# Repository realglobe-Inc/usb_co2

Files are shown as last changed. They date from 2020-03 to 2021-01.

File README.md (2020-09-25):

# usb_co2

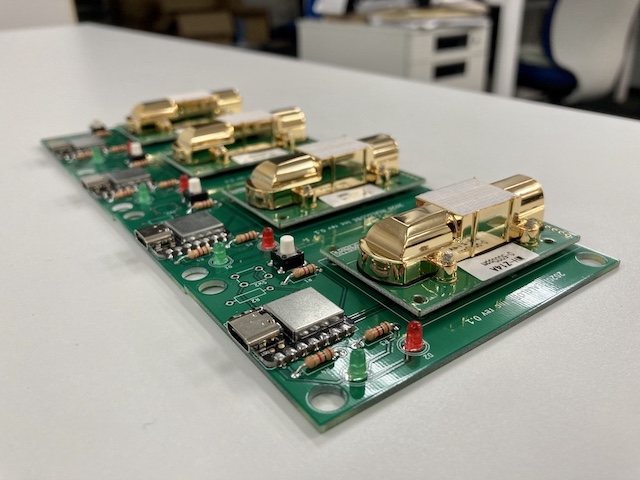
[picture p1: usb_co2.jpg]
usb_co2


Mac, LinuxマシンにUSBで接続できて追加ドライバ不要で値を読めるCO2センサ

## 使い方(macOS)

まず、USB機器をすべてコンピュータから取り外す。

次に、usb_co2をUSBポートに接続する。

次に、コンピュータに接続されているシリアルポートの一覧を表示する。

```
$ ls -1 /dev/cu.*
/dev/cu.Bluetooth-Incoming-Port
/dev/cu.iMiminashi5s-WirelessiAP
/dev/cu.usbmodem14101
```

上記の例の場合、`cu.usbmodem14101` というデバイスファイルがusb_co2を示す。

次に、`stty`コマンドを実行してシリアルポートの設定を行う。

```sh
stty -f /dev/cu.usbmodem14101 raw 9600
```

最後に、`cat`コマンドでデバイスファイルを読み込むとCO2の値(ppm)が表示される。

```
$ cat /dev/cu.usbmodem14101 
co2=399;status=0
co2=399;status=0
co2=399;status=0
co2=399;status=0
co2=399;status=0
co2=399;status=0
```

## 使い方(Linux)

まず、USB機器をすべてコンピュータから取り外す。

次に、usb_co2をUSBポートに接続する。

次に、コンピュータに接続されているシリアルポートの一覧を表示する。

```
$ ls -1 /dev/tty*
/dev/tty
.
. (中略)
.
/dev/ttyACM0
/dev/ttyAMA0
/dev/ttyprintk
/dev/ttyUSB0
```

上記の例の場合、`/dev/ttyACM0` というデバイスファイルがusb_co2を示す。

次に、`stty`コマンドを実行してシリアルポートの設定を行う。

```sh
stty -F /dev/ttyACM0 raw 9600
```

最後に、`cat`コマンドでデバイスファイルを読み込むとCO2の値(ppm)が表示される。

```
$ cat /dev/ttyACM0
co2=399;status=0
co2=399;status=0
co2=399;status=0
co2=399;status=0
co2=399;status=0
```

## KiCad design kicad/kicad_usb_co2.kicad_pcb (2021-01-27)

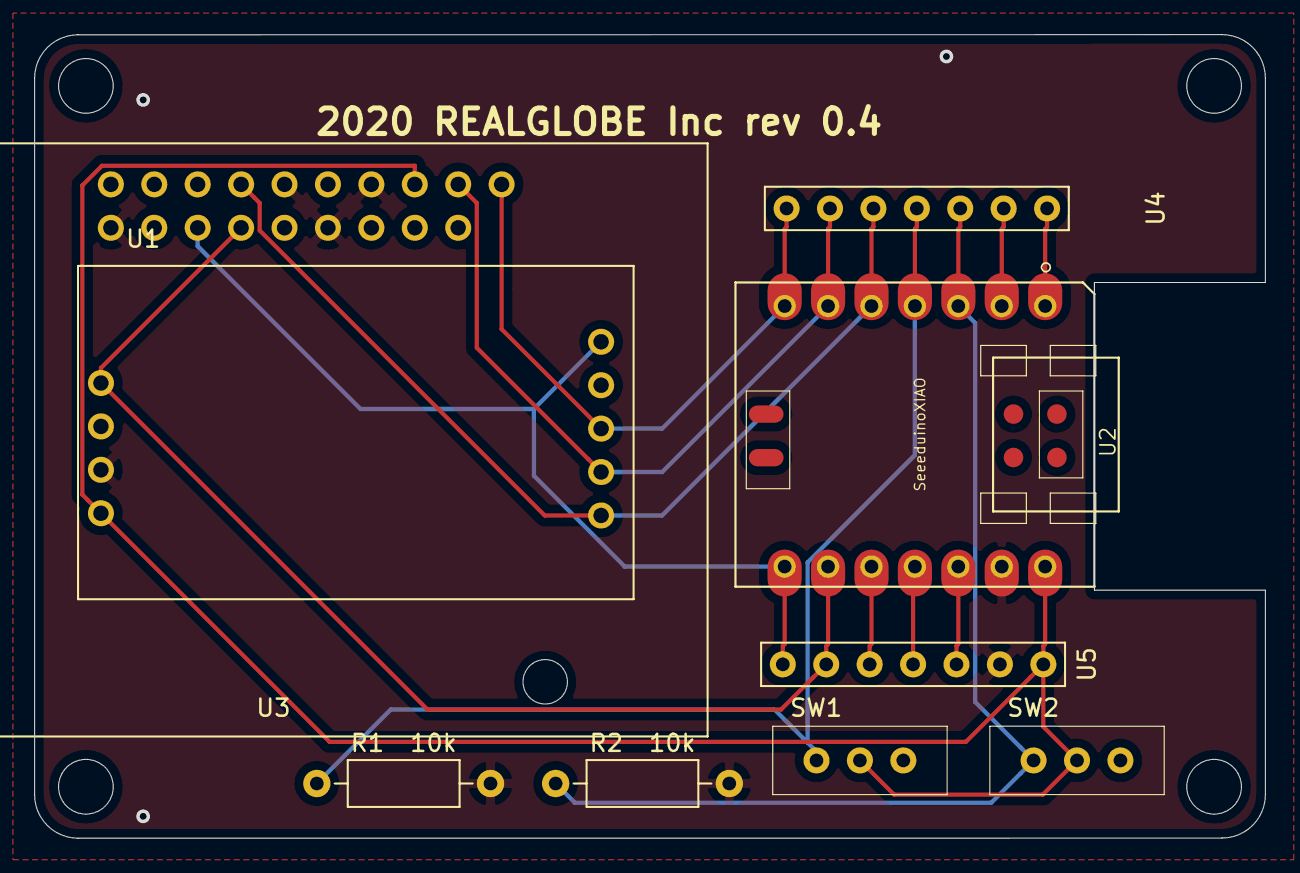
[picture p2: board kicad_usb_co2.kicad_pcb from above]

Board: 2 copper layers, 72.0 x 47.0 mm, 9 parts (0 on the bottom side), 14 nets.

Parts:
R1  10k, R2  10k: R; R_Axial_DIN0207_L6.3mm_D2.5mm_P10.16mm_Horizontal
SW1, SW2: SW_SPDT; SW_SLIDE_sengoku
U1: MH-Z19B
U2: SeeeduinoXIAO; SeeedXIAO
U3: MH-Z14A
U4, U5: PinHeader_XIAO

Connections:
+5V: SW1.2, SW2.2, U1.9, U2.14, U3.17, U5.7
GND: R1 10k.2, R2 10k.2, U1.8, U2.13, U3.2, U3.3, U3.12, U3.16, U5.6
unnamed: R1 10k.1, SW1.1, U2.4, U4.4
unnamed: R2 10k.1, SW2.1, U2.3, U4.3
unnamed: U1.1, U2.8, U3.8, U5.1
unnamed: U1.3, U2.7, U3.19, U4.7
unnamed: U1.4, U2.6, U3.18, U4.6
unnamed: U1.5, U2.5, U3.5, U4.5
unnamed: U1.6, U2.9, U3.6, U5.2
unnamed: U2.1, U4.1
unnamed: U2.2, U4.2
unnamed: U2.10, U5.3
unnamed: U2.11, U5.4
unnamed: U2.12, U5.5

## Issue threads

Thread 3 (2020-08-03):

LEDなどの外付け部品をなくしたい

miminashi, 2020-08-03:
- #2 の確認作業でLEDのはんだ付けしてみたら意外と手間だったのでなくしたい
- XIAOにユーザ定義LEDついてるからこれを使うことにして、基本構成では外付けLEDは無しにしたい
- 短く2連続点滅して1秒消灯（校正中） -> 点灯（校正完了） みたいな感じがよいかも

urib0, 2020-08-04:
ソフト酒精のみ

urib0, 2020-09-17:
とりあえず自動校正で行くのでclose
https://github.com/realglobe-Inc/usb_co2/issues/13

urib0, 2020-09-17:
対応済み
https://github.com/realglobe-Inc/usb_co2/pull/16

Closed 2020-09-17.

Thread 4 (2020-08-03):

校正モードにはいる操作をタクトスイッチではなくジャンパにしたい

miminashi, 2020-08-03:
- タクトスイッチつけてみて思ったのが、「ケーブル挿すときに押さないように気をつかってしまう」
- 「スイッチ押しながらケーブル挿す」は回路屋さんだと当たり前かもしれないけど普通に高等テクだと思う
- ジャンパだと RUN <-> CALIB のような表記がシルクでできる（タクトスイッチでも press to calib とか書けるっちゃ書けるが）
- 複数個やるときの作業性はそれぞれ一短一長で大差ないかも

一方、タクトスイッチのメリットとしては、

- 校正モードにしたあと位置を戻さなくていい
- ジャンパをなくす心配がない

などでしょうかね。

urib0, 2020-08-03:
ちょうど昨日8/3に基板の微修正を行ったので、上記も盛り込んだやつを発注しますか

urib0, 2020-08-04:
スライドスイッチに交換

miminashi, 2020-08-15:
@urib0 すみません今気づきました。
もしまだ未発注なら上記も含めてお願いします🙏
発注済なら次回で！

urib0, 2020-09-17:
修正/発注/動作確認済みの為close

Closed 2020-09-17.

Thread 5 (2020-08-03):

実際の校正開始まで猶予をもたせたほうがいい？

miminashi, 2020-08-03:
- 校正開始のタイミングでCO2源（=人間）がすぐ横にいるので、実際の校正開始まで数分待ったほうがいい？
- MH-Z14Aがもともとそういう処理をしていたら必要ない
- 実験してみないとわからんけど、予防的につけておいてもいいかも

urib0, 2020-08-03:
すでに校正モード開始から30分の猶予をもたせていますが、もう少し長くしたほうがいいですか?

miminashi, 2020-08-15:
あ、すみません、MH-Z14Aの仕様をあんまり理解してませんでした。

https://qiita.com/urib0/items/256973f68cc1fbcd1244#0x87%E3%82%BC%E3%83%AD%E7%82%B9%E6%A0%A1%E6%AD%A3
>  400[ppm]のCO2で満たした箱等に入れるか屋外で20分以上稼働させた後にこのコマンドを送る

だから、現状の挙動で問題なさそうです。
closeします。

Closed 2020-08-15.

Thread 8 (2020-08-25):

測定値のドリフトをチェックする

miminashi, 2020-08-25:
- MH-Z14Aのデータシート見ても値がどのくらいドリフトするのかわからないので、ドリフトを測定してみる
- 密閉した容器の中で数日程度動かしてみればよい？
- [村田製作所が自社製品との比較用に用いたセンサ](https://www.murata.com/ja-jp/products/sensor/co2/technicalinfo)のように40日で100ppm以上ドリフトするようなら、手動校正するのやめて自動校正をさせたほうがよさそう

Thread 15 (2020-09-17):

シリアル出力のフォーマットを変える

urib0, 2020-09-17:
下記の形式にする、statusは正常を"0"、異常を"0"以外で表す
co2=XXX;status=X
現状ではMH-Z14Aから受信したデータのチェックサムを見ていないので、"0"を固定で返す

urib0, 2020-09-17:
対応済み
https://github.com/realglobe-Inc/usb_co2/pull/16

Closed 2020-09-17.

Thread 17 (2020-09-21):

シリアル出力の改行コードをCRLFからLFにする

miminashi, 2020-09-21:
- シェル上でCRLFなのかLFなのかわからないのでハマった
- トラブルを少なくするためにLFに統一したい
- `println('hoge')`を`print(`hoge\n')`になおしていくだけ

kirisaki, 2020-09-22:
通信って CRLF に寄せるのが基本じゃなかったでしたっけ

kirisaki, 2020-09-23:
ああ、でも CRLF だと正規表現で取り出すのがめんどっちいのか……

urib0, 2020-09-25:
正規表現分からないのでめんどっちさが分かりませんが、LFに修正します

Closed 2020-10-28.

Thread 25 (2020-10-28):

電源CO2センサに供給する電圧が間違っている

urib0, 2020-10-28:
本来は3.3Vのところ5Vになっている

5Vにリワークすると、出力値が4,5千のままだった個体もある程度正常な値を出すようになったので、今までの個体差は電圧が原因と考えられる

urib0, 2020-11-16:
対応済みなのでclose
https://github.com/realglobe-Inc/heceye_pmf/issues/178

Closed 2020-11-16.

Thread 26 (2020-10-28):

ロータリースイッチでIDを選択できるようにする

miminashi, 2020-10-28:
- 同じ種類のセンサを複数個接続する場合、現状だと識別する手段が無いので、IDを設定できるようにする
- IDは4bit（ただしメッセージには1~16の整数として出力する）
- こんな感じのスイッチをつける https://akizukidenshi.com/catalog/g/gP-06574/
- `id=1;co2=410;status=0` のような感じで出力メッセージにIDを出力する

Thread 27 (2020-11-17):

MH-Z19Bの値が定期的に257になる

urib0, 2020-11-17:
恐らくだけどMH-Z19Bが5秒毎に値を更新する動作と、マイコンから値をリードするタイミングが被ると異常値が出るのではないか？という気がする

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

urib0, 2020-11-17:
修正済み、マージされたらcloseする
https://github.com/realglobe-Inc/usb_co2/pull/28

urib0, 2020-12-02:
マージされたのでcloseする

Closed 2020-12-02.

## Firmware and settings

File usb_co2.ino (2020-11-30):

#define LED_ON LOW
#define LED_OFF HIGH
#define PIN_SW1 3
#define PIN_SW2 2
#define INTERVAL_UPDATE 1000
#define INTERVAL_LOOP 1
#define SERIAL_TX_MARGIN 13

void setup() {
  digitalWrite(LED_BUILTIN, LED_OFF);
  pinMode(LED_BUILTIN, OUTPUT);
  pinMode(PIN_SW1, INPUT);
  pinMode(PIN_SW2, INPUT);

  Serial.begin(9600);
  while (!Serial) {
    ; // wait for serial port to connect
  }

  usb_mhz14a_init();
/*
  if( digitalRead( PIN_SW1 ) ){
    digitalWrite(LED_BUILTIN, LED_ON);
    usb_mhz14a_zero_calibration();
    digitalWrite(LED_BUILTIN, LED_OFF);
  }
*/
  digitalWrite(LED_BUILTIN, LED_ON);
}

void loop() {
  int value = 0;
  int status = 0;
  static int interval_cnt = INTERVAL_UPDATE;

  if( 0 >= interval_cnt ){
    usb_mhz14a_co2_request();
  }
  else if( 0 == usb_mhz14a_co2_is_ready() ){
    status = usb_mhz14a_get_co2( &value );
    Serial.print("co2=");
    if( 0 == status ){
      Serial.print(value, DEC);
    }
    Serial.print(";status=");
    Serial.print(status);
    Serial.print("\n");
  }

  if( 0 >= interval_cnt ){
    interval_cnt = INTERVAL_UPDATE - SERIAL_TX_MARGIN;
  }
  interval_cnt -= INTERVAL_LOOP;

  delay( INTERVAL_LOOP );
}

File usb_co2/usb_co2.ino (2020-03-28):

#include <SoftwareSerial.h>

//SoftwareSerial mySerial(14, 15); // RX, TX for WNPink
SoftwareSerial mySerial(16, 10); // RX, TX for ProMicro

void setup() {
  Serial.begin(9600);
  while (!Serial) {
    ; // wait for serial port to connect
  }
  mySerial.begin(9600);
}

void loop() {
  byte command[] = {
    0xFF,  // Byte 0
    0x01,  // Byte 1
    0x86,  // Byte 2
    0x00,  // Byte 4
    0x00,  // Byte 5
    0x00,  // Byte 6
    0x00,  // Byte 7
    0x00,  // Byte 8
    0x79   // Byte 9
  };
  mySerial.write(command, sizeof(command));

  delay(100);

  int c = 0;
  int message[9];

  while (mySerial.available()) {
    int b = mySerial.read();
    if ((c == 0 && b == 0xFF) || (c >= 1 && c <= 8)) {
      message[c] = b;
      c++;
    }
  }

  int high_byte = message[2];
  int low_byte = message[3];
  int value = high_byte * 256 + low_byte;
  Serial.print("co2=")
  Serial.println(value, DEC);

  delay(900);
}

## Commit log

2020-03-28 ProMicroに対応した
2020-03-30 出力フォーマットを変更した
2020-05-25 Seeduino XIAOに対応した
2020-06-22 kicadのデータ作った
    [kicad_usb_co2.kicad_pcb, kicad_usb_co2.sch]
2020-07-08 不要なファイルを削除
2020-07-08 不要なので削除
2020-07-28 MH-Z14Aの制御を別ファイルに移動
2020-07-28 MH-Z14Aのinit するの忘れてた
2020-07-28 MH-Z14Aの送信-受信待ちは実測3msなので100→10msへ変更
2020-07-28 送信コマンドをファイルスコープにした
2020-07-28 起動時にMH-Z14Aの自動校正機能(ABC)をOFFにするコードを追加
2020-07-28 ゼロ校正関数を追加
2020-07-31 ゼロ校正関数内で１秒毎にCO2値を空読みして30分経過後ゼロ校正をするよう変更
2020-07-31 LEDとスイッチの定義と初期化を追加
2020-07-31 SW1押下しながらの起動でゼロ校正をする
2020-08-03 基板四隅の面取りとネジ穴をM3にした
    [kicad_usb_co2.kicad_pcb]
2020-08-04 MH-Z14Aのフットプリントを更新
    [kicad_usb_co2.kicad_pcb]
2020-08-16 画像を追加した
2020-08-16 markdownの誤記をなおした
2020-08-16 画像の大きさを変更した
2020-08-19 LEDを削除、タクトスイッチからトグルスイッチに変更
    [kicad_usb_co2.sch]
2020-08-20 ガーバー出力オプション変更
    [kicad_usb_co2.kicad_pcb]
2020-09-17 自動校正をONにする関数の追加
2020-09-17 起動時に自動校正をOFFにするのをやめた
2020-09-17 手動校正モードに入らないようにした
2020-09-17 外付けLEDを無くしてボード上のLEDを使用するようにした
2020-09-17 シリアル接続を確立してからセンサの初期化をするようにした
2020-09-17 シリアル出力にステータスをつけた
2020-09-21 READMEに使い方を記載した
2020-09-21 Linux版の使い方を記載した
2020-09-25 シリアル出力の改行コードを変更した
2020-10-02 kicadのファイルをMH-Z14AとMH-Z19Bで分けた
    [kicad_usb_co2.kicad_pcb, kicad_usb_co2.sch]
2020-10-02 MH-Z14Aのファイルをコピーした
    [kicad_usb_co2.kicad_pcb, kicad_usb_co2.sch]
2020-10-05 MH-Z14A→MH-Z19Bへ置き換え、ERC OK、フットプリント関連付けはまだ
    [kicad_usb_co2.sch]
2020-10-15 スキーマ引き直した
    [kicad_usb_co2.sch]
2020-10-15 センサの電源を3.3Vから5Vに変えた
    [kicad_usb_co2.sch]
2020-10-15 配置配線ok DRCok
    [kicad_usb_co2.kicad_pcb]
2020-10-15 ちょっといじっちゃったので戻した
2020-10-15 バージョンがrev 0.2 のままだったので、0.1に治した
    [kicad_usb_co2.kicad_pcb]
2020-10-23 ABCをonにするつもりでoffにしている箇所を修正した
2020-10-23 なんもなおせてなかった
2020-10-28 kicadのフォルダをMH-Z14Aと19Bと共通にした
    [kicad_usb_co2.kicad_pcb, kicad_usb_co2.sch]
2020-10-28 スキーマにMH-Z14AとMH-Z19Bを共存させた
    [kicad_usb_co2.sch]
2020-10-28 XIAOのピンをすべてピンヘッダに出した
    [kicad_usb_co2.sch]
2020-10-28 ピンヘッダのフットプリントが関連付いてなかった
    [kicad_usb_co2.sch]
2020-10-28 色々フットプリントが関連付いてなかった
    [kicad_usb_co2.sch]
2020-10-28 基板外形の修正と仮配置
    [kicad_usb_co2.kicad_pcb]
2020-10-28 たぶん動く
    [kicad_usb_co2.kicad_pcb]
2020-10-30 シルクのリビジョンをインクリした
    [kicad_usb_co2.kicad_pcb]
2020-11-09 配列の初期化忘れ
2020-11-09 CO2値を戻り値でなく参照渡しにした
2020-11-11 ドライバ側で時間を持たないようにした(ノンブロッキングにした9
2020-11-11 ドライバの修正に合わせた
2021-01-27 MH-Z19のスルーホールを大きくした
    [kicad_usb_co2.kicad_pcb]
2021-01-27 抵抗の容量をシルクで書いた
    [kicad_usb_co2.kicad_pcb]
2021-01-27 基板リビジョンシルクをインクリメントした
    [kicad_usb_co2.kicad_pcb]
